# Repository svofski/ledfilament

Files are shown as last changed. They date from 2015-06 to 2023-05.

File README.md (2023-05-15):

# ledfilament
ATtiny12L 75V LED Filaments driver

These are flexible LED filaments, of which I learned from [this video](http://www.youtube.com/watch?v=H_XiunR-cAQ)
by [mikeselectricstuf](http://www.electricstuff.co.uk/) 
They require around 75V to light up, so a for 
these LEDs is essentially the same as Nixie tube driver, which is awesome.

My favourite shape

Using any serious microcontroller for this experiment would be wasteful. Fortunately, I had
an ATtiny12L salvaged from an ink cartridge. Unfortunately, avr-gcc would not even
generate code for it. Fortunately, its task is so simple that it wasn't a trouble at all
to code it in assembly.

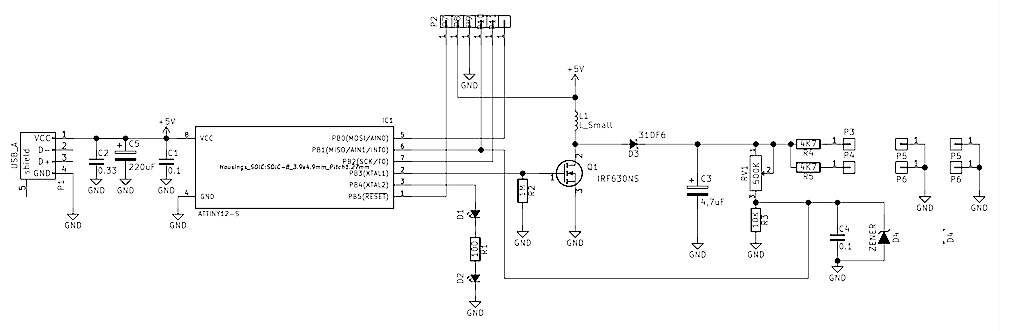
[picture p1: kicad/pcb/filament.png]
circuit

This is a boost converter. R2 is a bleed resistor that does not let the MOSFET to stay open 
when the micro is being programmed. The inductor value is anything around 100uH. The 
feedback loop to keep the voltage at set value is implemented using resistor divider
`RV1-R3` and the builtin comparator of ATtiny12L. 

It was also an experiment with homemade UV soldermask. I did not get it at first attempt, 
but it worked out nicely after a few attempts. As usual with UV curable things, the trick 
is to have opaque zones in the transparency really opaque.
Red soldermask

-----
2015 Viacheslav Slavinsky https://www.sensi.org/~svo

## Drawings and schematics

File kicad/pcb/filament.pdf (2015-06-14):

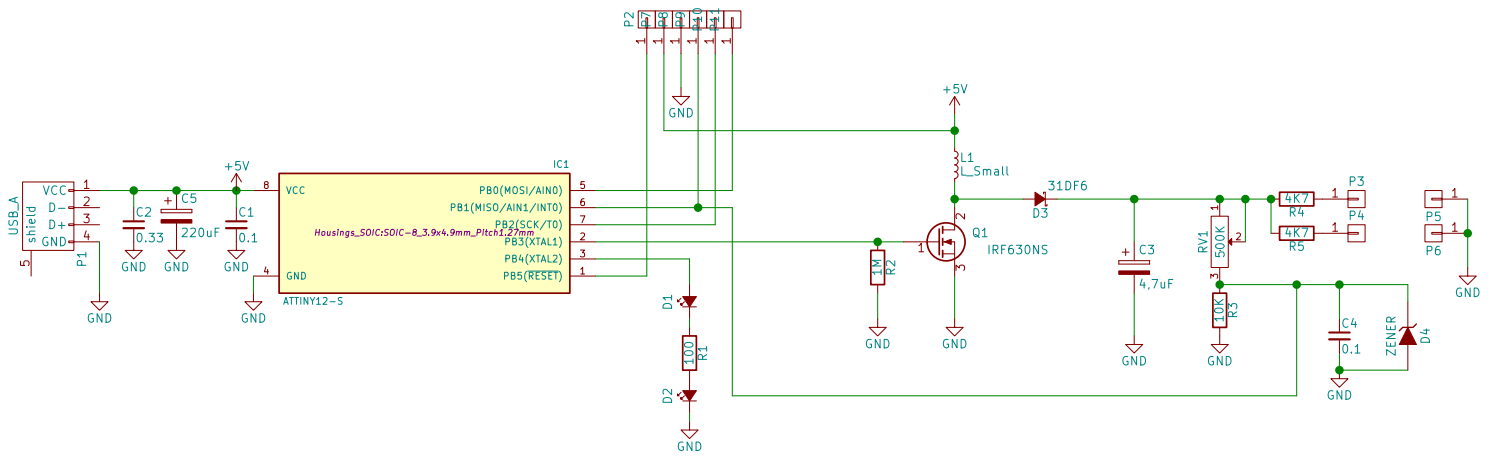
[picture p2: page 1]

Id: 1/1 Title: File: filament.sch Sheet: /

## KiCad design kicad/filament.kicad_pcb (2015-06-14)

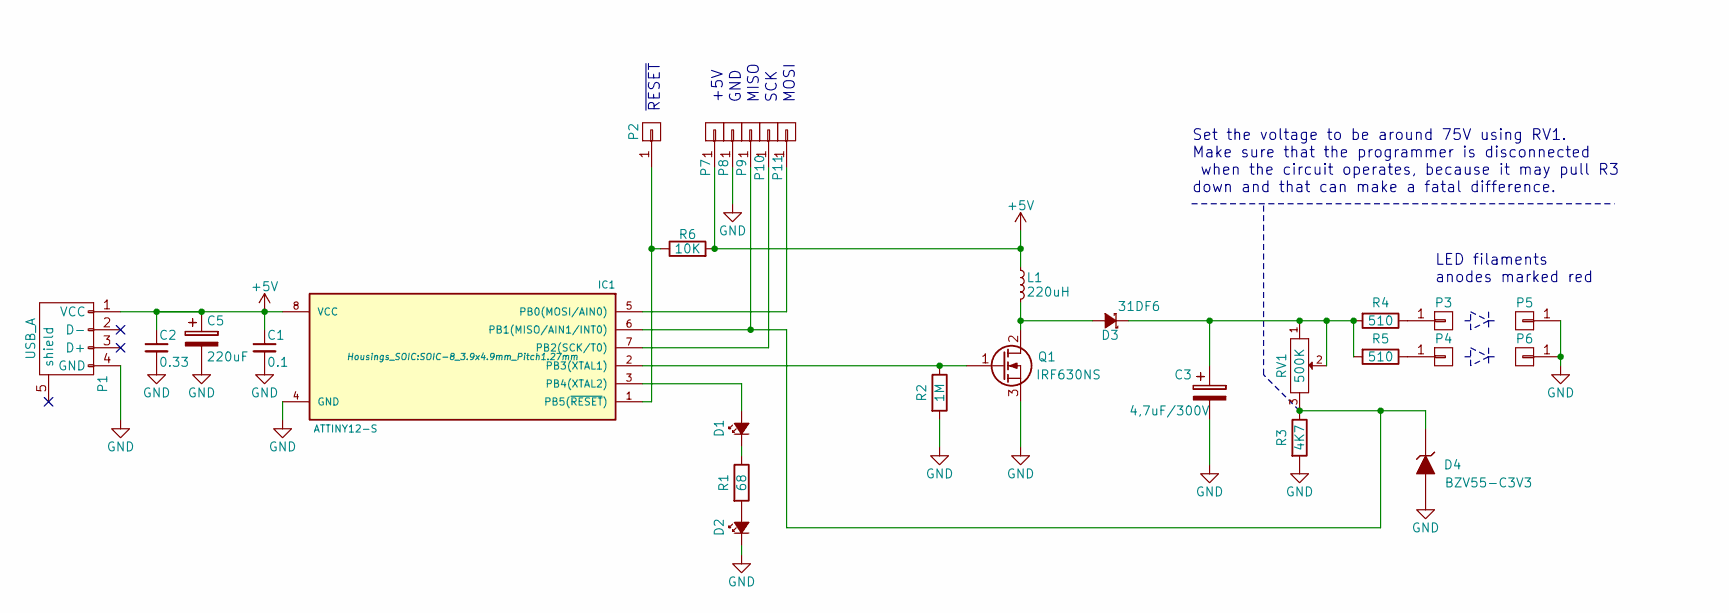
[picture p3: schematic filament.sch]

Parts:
C1: 0.1; C_0402
C2: 0.33; C_0805
C3: 4,7uF/300V; Elko_vert_20x10mm_RM5
C5: 220uF; TantalC_SizeC_EIA-6032_Reflow
D1, D2: Led_Small; LED-0603
D3: 31DF6; diode_do201
D4: BZV55-C3V3; sod80c
IC1: ATTINY12-S; SOIC-8_3.9x4.9mm_Pitch1.27mm
L1: 220uH; SELF-WE-PD-XXL
P1: USB_A; USBPCB
P2, P7, P8, P9, P10, P11: CONN_01X01; wirepad-1
P3, P4, P5, P6: CONN_01X01; Pin_Header_Straight_1x01
Q1: IRF630NS; d2-pak
R1: 68; R_0805
R2: 1M; R_0805
R3: 4K7; R_0805
R4, R5: 510; R_0805
R6: 10K; R_0805
RV1: 500K; trim_bourns_3214j

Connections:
+5V: C1.1, C2.1, C5.1, IC1.8 (VCC), L1.1, P1.1 (VCC), P7.1, R6.2
GND: C1.2, C2.2, C3.2, C5.2, D2.1 (K), D4.2 (A), IC1.4 (GND), P1.4 (GND), P5.1, P6.1, P8.1, Q1.3 (S), R2.2, R3.2
unnamed: C3.1, D3.1 (K), R4.2, R5.2, RV1.1, RV1.2
unnamed: D1.1 (K), R1.1
unnamed: D1.2 (A), IC1.3 (PB4(XTAL2))
unnamed: D2.2 (A), R1.2
unnamed: D3.2 (A), L1.2, Q1.2 (D)
unnamed: D4.1 (K), IC1.6 (PB1(MISO/AIN1/INT0)), P9.1, R3.1, RV1.3
unnamed: IC1.1 (PB5(~RESET~)), P2.1, R6.1
unnamed: IC1.2 (PB3(XTAL1)), Q1.1 (G), R2.1
unnamed: IC1.5 (PB0(MOSI/AIN0)), P11.1
unnamed: IC1.7 (PB2(SCK/T0)), P10.1
unnamed: P3.1, R4.1
unnamed: P4.1, R5.1

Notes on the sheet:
LED filaments anodes marked red
Set the voltage to be around 75V using RV1. Make sure that the programmer is disconnected when the circuit operates, because it may pull R3 down and that can make a fatal difference.
~RESET
+5V
GND
MISO
SCK
MOSI

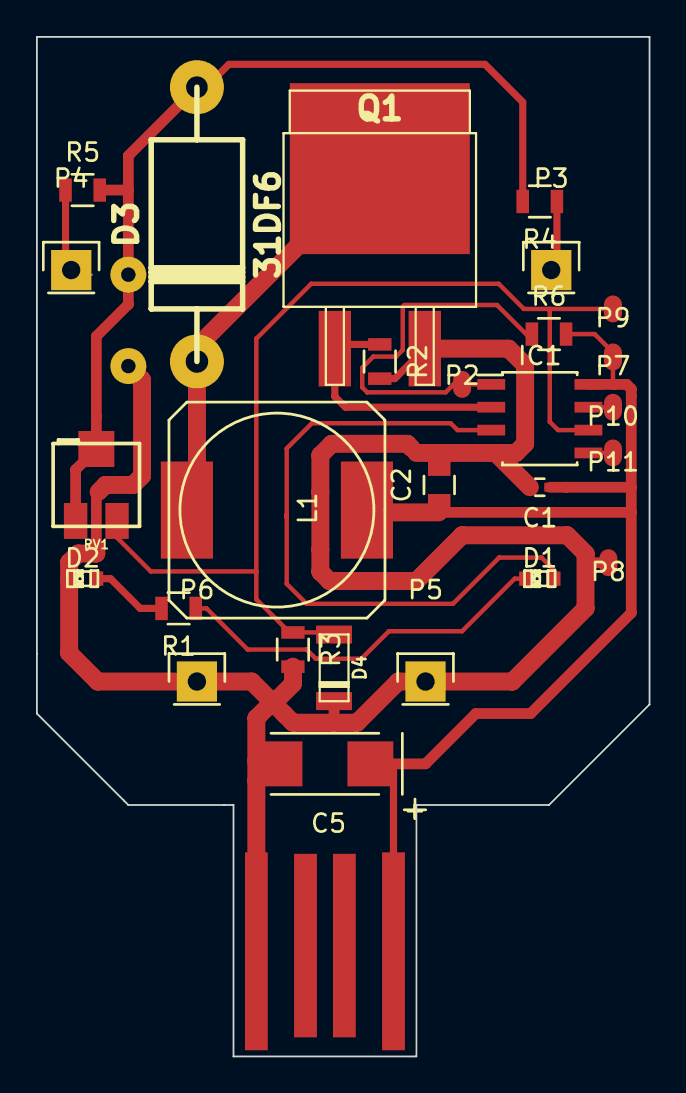
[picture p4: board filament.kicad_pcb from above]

Board: 2 copper layers, 34.0 x 56.6 mm, 29 parts (1 on the bottom side), 14 nets.

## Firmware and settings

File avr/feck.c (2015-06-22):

#include <avr/io.h>

#define FREQ 35000L
#define DUTY 25

#define WINKBLINK 17500

#define PERIOD  ((F_CPU)/(FREQ))
#define ONDUTY  ((PERIOD) * (DUTY) / 100) 
#define OFFDUTY ((PERIOD) * (100-DUTY) / 100)

#define PUMP 3
#define NIPPLES 4

void ConfigureIO()
{
    // outputs
    DDRB |= _BV(NIPPLES) | _BV(PUMP);
    PORTB = 0;

    // analog comparator 
    // + = AIN0 = Internal voltage reference = 1.22V
    // - = AIN1 = PB1 
    // if AIN0 > AIN1: AC = 1 
    //   while AC == 1: pump
    //   when PB1 > 1.22, AC == 0: don't pump
    ACSR = _BV(AINBG); // enable comparator, enable bandgap reference
}

void Pumpor()
{
    static uint16_t blinkctr = 0;

    for(;;) {
        PORTB |= _BV(PUMP);
        _delay_us(ONDUTY);
        PORTB &= _BV(PUMP);
        _delay_us(OFFDUTY);

        if (blinkctr-- == 0) {
            blinkctr = WINKBLINK;
            PORTB ^= _BV(NIPPLES);
        }
    }
}

void main()
{
    ConfigureIO();
    Pumpor();
}

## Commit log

2015-06-14 tiny12l-based charge pump LED filament driver
    [filament.kicad_pcb, filament.sch]
2015-09-10 circuito png
